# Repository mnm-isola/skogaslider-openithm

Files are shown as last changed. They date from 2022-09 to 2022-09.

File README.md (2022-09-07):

# WIP DO NOT USE

Skogaslider PCB designed as a drop in replacement for existing Openithm controller

With a RP2040-Zero, 3 MPR121 breakout modules and a 74HC4051 breakout module

Should have compatibility with analog air towers and digital air towers.

6 pots for adjusting photodiodes instead of trying through different resistor values.

[skogaslider](https://github.com/skogaby/skogaslider)

Note: RPi Pico is too long to fit

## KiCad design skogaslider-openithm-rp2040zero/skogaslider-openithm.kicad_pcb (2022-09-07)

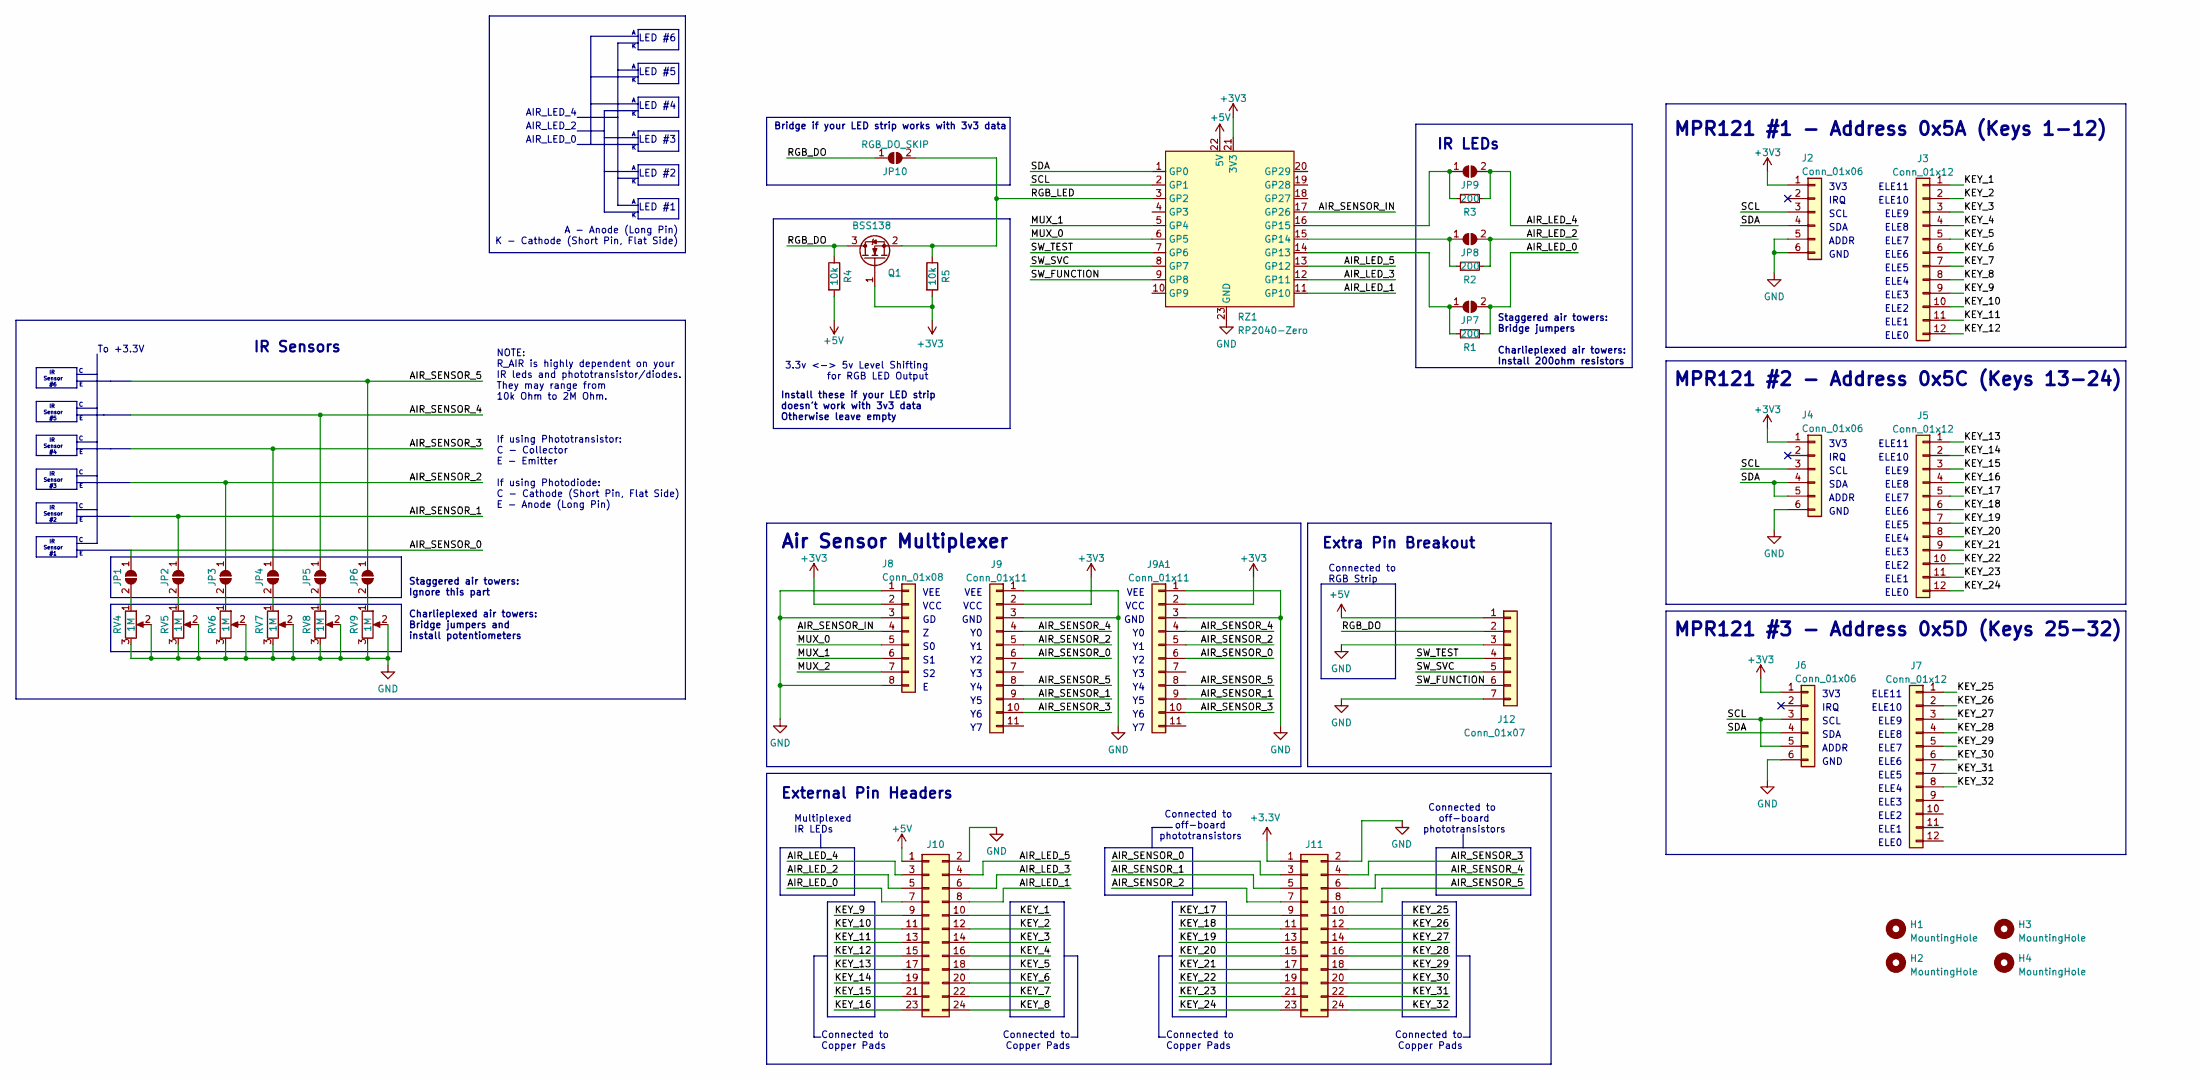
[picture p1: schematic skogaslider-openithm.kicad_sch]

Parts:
H1, H2, H3, H4: MountingHole; MountingHole_3.2mm_M3
J2, J4, J6: Conn_01x06; PinSocket_1x06_P2.54mm_Vertical
J3, J5, J7: Conn_01x12; PinSocket_1x12_P2.54mm_Vertical
J8: Conn_01x08; PinSocket_1x08_P2.54mm_Vertical
J9, J9A1: Conn_01x11; PinSocket_1x11_P2.54mm_Vertical
J10, J11: Conn_02x12_Odd_Even; PinHeader_2x12_P2.54mm_Horizontal
J12: Conn_01x07; PinHeader_1x07_P2.54mm_Vertical
JP1, JP2, JP3, JP4, JP5, JP6: AIR_MPLEX_JUMPER; SolderJumper-2_P1.3mm_Open_RoundedPad1.0x1.5mm
JP7, JP8, JP9: IR_STAG_JUMPER; SolderJumper-2_P1.3mm_Open_RoundedPad1.0x1.5mm
JP10: RGB_DO_SKIP; SolderJumper-2_P1.3mm_Open_RoundedPad1.0x1.5mm
Q1: BSS138; SOT-23
R1, R2, R3: 200; R_Axial_DIN0204_L3.6mm_D1.6mm_P5.08mm_Horizontal
R4, R5: 10k; R_0805_2012Metric_Pad1.20x1.40mm_HandSolder
RV4, RV5, RV6, RV7, RV8, RV9: 1M; Potentiometer_Runtron_RM-065_Vertical
RZ1: RP2040-Zero

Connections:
+5V: J10.1, J12.1, R4.2, RZ1.22 (5V)
/AIR_LED_0: J10.7, JP7.2 (B), R1.2
/AIR_LED_1: J10.8, RZ1.11 (GP10)
/AIR_LED_2: J10.5, JP8.2 (B), R2.2
/AIR_LED_3: J10.6, RZ1.12 (GP11)
/AIR_LED_4: J10.3, JP9.2 (B), R3.2
/AIR_LED_5: J10.4, RZ1.13 (GP12)
/AIR_SENSOR_0: J9.6, J9A1.6, J11.3, JP1.1 (A)
/AIR_SENSOR_1: J9.9, J9A1.9, J11.5, JP2.1 (A)
/AIR_SENSOR_2: J9.5, J9A1.5, J11.7, JP3.1 (A)
/AIR_SENSOR_3: J9.10, J9A1.10, J11.4, JP4.1 (A)
/AIR_SENSOR_4: J9.4, J9A1.4, J11.6, JP5.1 (A)
/AIR_SENSOR_5: J9.8, J9A1.8, J11.8, JP6.1 (A)
/AIR_SENSOR_IN: J8.4, RZ1.17 (GP26)
/KEY_1: J3.1, J10.10
/KEY_2: J3.2, J10.12
/KEY_3: J3.3, J10.14
/KEY_4: J3.4, J10.16
/KEY_5: J3.5, J10.18
/KEY_6: J3.6, J10.20
/KEY_7: J3.7, J10.22
/KEY_8: J3.8, J10.24
/KEY_9: J3.9, J10.9
/KEY_10: J3.10, J10.11
/KEY_11: J3.11, J10.13
/KEY_12: J3.12, J10.15
/KEY_13: J5.1, J10.17
/KEY_14: J5.2, J10.19
/KEY_15: J5.3, J10.21
/KEY_16: J5.4, J10.23
/KEY_17: J5.5, J11.9
/KEY_18: J5.6, J11.11
/KEY_19: J5.7, J11.13
/KEY_20: J5.8, J11.15
/KEY_21: J5.9, J11.17
/KEY_22: J5.10, J11.19
/KEY_23: J5.11, J11.21
/KEY_24: J5.12, J11.23
/KEY_25: J7.1, J11.10
/KEY_26: J7.2, J11.12
/KEY_27: J7.3, J11.14
/KEY_28: J7.4, J11.16
/KEY_29: J7.5, J11.18
/KEY_30: J7.6, J11.20
/KEY_31: J7.7, J11.22
/KEY_32: J7.8, J11.24
/MUX_0: J8.5, RZ1.6 (GP5)
/MUX_1: J8.6, RZ1.5 (GP4)
/MUX_2: J8.7
/RGB_DO: J12.2, JP10.1 (A), Q1.3 (D), R4.1
/RGB_LED: JP10.2 (B), Q1.2 (S), R5.1, RZ1.3 (GP2)
/SCL: J2.3, J4.3, J6.3, J6.5, RZ1.2 (GP1)
/SDA: J2.4, J4.4, J4.5, J6.4, RZ1.1 (GP0)
/SW_FUNCTION: J12.6, RZ1.9 (GP8)
/SW_SVC: J12.5, RZ1.8 (GP7)
/SW_TEST: J12.4, RZ1.7 (GP6)
GND: J2.5, J2.6, J4.6, J6.6, J8.1, J8.3, J8.8, J9.1, J9.3, J9A1.1, J9A1.3, J10.2, J11.2, J12.3, J12.7, RV4.2, RV4.3, RV5.2, RV5.3, RV6.2, RV6.3, RV7.2, RV7.3, RV8.2, RV8.3, RV9.2, RV9.3, RZ1.23 (GND)
unnamed: JP1.2 (B), RV4.1
unnamed: JP2.2 (B), RV5.1
unnamed: JP3.2 (B), RV6.1
unnamed: JP4.2 (B), RV7.1
unnamed: JP5.2 (B), RV8.1
unnamed: JP6.2 (B), RV9.1
unnamed: JP7.1 (A), R1.1, RZ1.14 (GP13)
unnamed: JP8.1 (A), R2.1, RZ1.15 (GP14)
unnamed: JP9.1 (A), R3.1, RZ1.16 (GP15)

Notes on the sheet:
ELE4
IRQ
VEE
ELE10
LED #5
SDA
3.3v <-> 5v Level Shifting for RGB LED Output
IR Sensors
ELE3
IR Sensor #5
IR LEDs
IR Sensor #3
ELE2
LED #2
Install these if your LED strip doesn't work with 3v3 data Otherwise leave empty
ELE1
ELE9
MPR121 #1 - Address 0x5A (Keys 1-12)
MPR121 #2 - Address 0x5C (Keys 13-24)
ADDR
LED #4
Connected to Copper Pads
SCL
GND
ELE6
Staggered air towers: Bridge jumpers Charlieplexed air towers: Install 200ohm resistors
Extra Pin Breakout
VCC
ELE8
ELE0
GND
Connected to off-board phototransistors
A - Anode (Long Pin) K - Cathode (Short Pin, Flat Side)
Connected to RGB Strip
IR Sensor #2
If using Phototransistor: C - Collector E - Emitter If using Photodiode: C - Cathode (Short Pin, Flat Side) E - Anode (Long Pin)
ELE5
To +3.3V
IR Sensor #6
MPR121 #3 - Address 0x5D (Keys 25-32)

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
Board: 2 copper layers, 39 parts (13 on the bottom side), 66 nets, no tracks yet.
